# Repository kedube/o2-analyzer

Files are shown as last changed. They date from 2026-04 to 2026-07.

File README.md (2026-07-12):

# O2 Analyzer Firmware

PlatformIO firmware for an Arduino-based nitrox / oxygen analyzer with a 128x64 SSD1306 OLED, ADS1115 ADC, buzzer feedback, EEPROM-backed calibration, and a single-button UI. The code is originally based on [Eunjae Im's OLED nitrox analyzer project](http://ejlabs.net/arduino-oled-nitrox-analyzer). 

This firmware accompanies the Divetech nitrox analyzer enclosure designed by Tony Land and is intended to build cleanly in Visual Studio Code with current PlatformIO and Adafruit libraries.

## Images

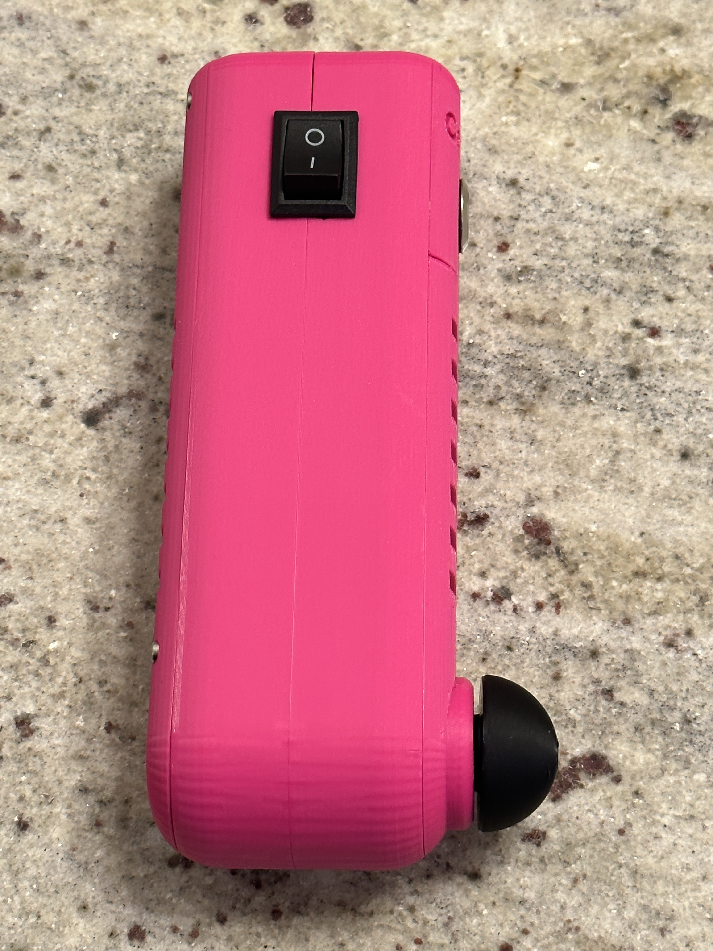
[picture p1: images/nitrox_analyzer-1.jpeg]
O2 analyzer front view


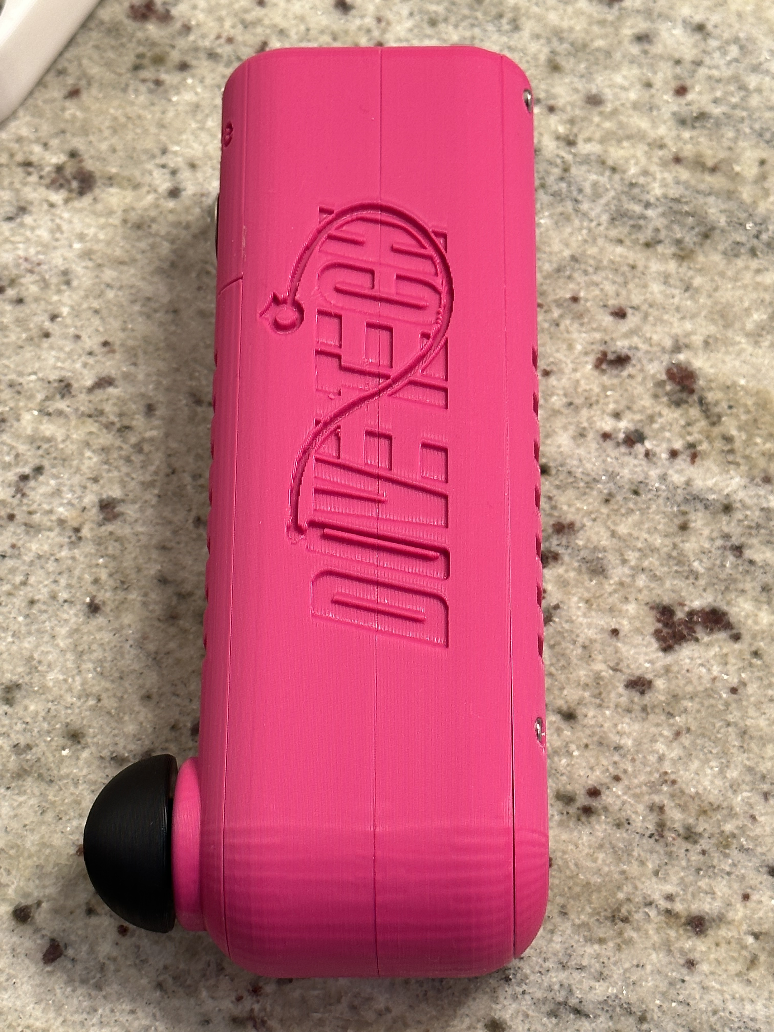
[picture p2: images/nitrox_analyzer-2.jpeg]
O2 analyzer display close-up


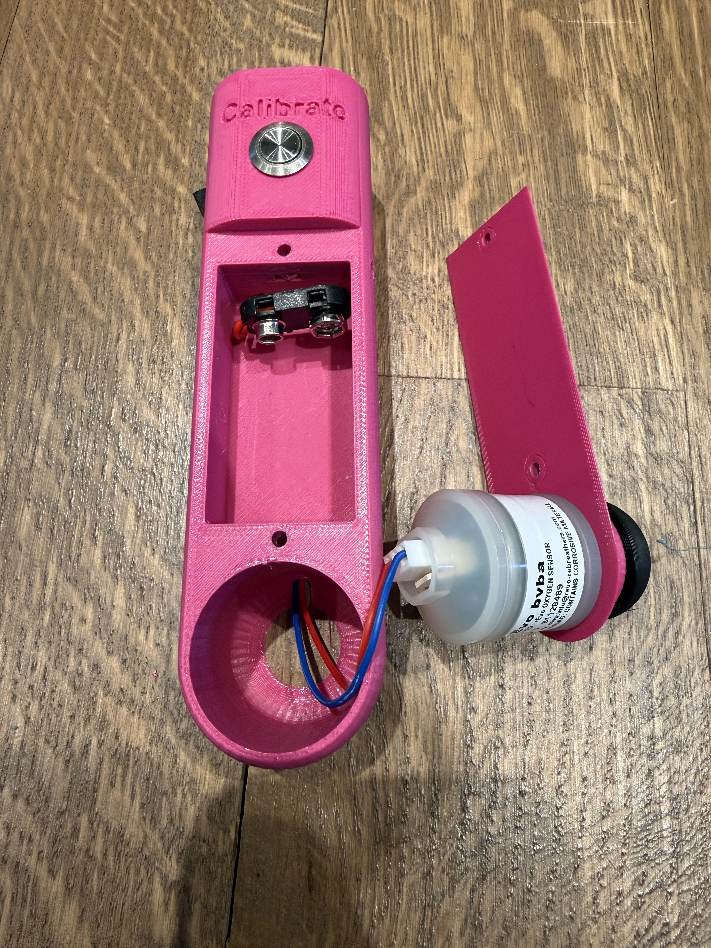
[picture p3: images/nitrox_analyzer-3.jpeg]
O2 analyzer internal wiring


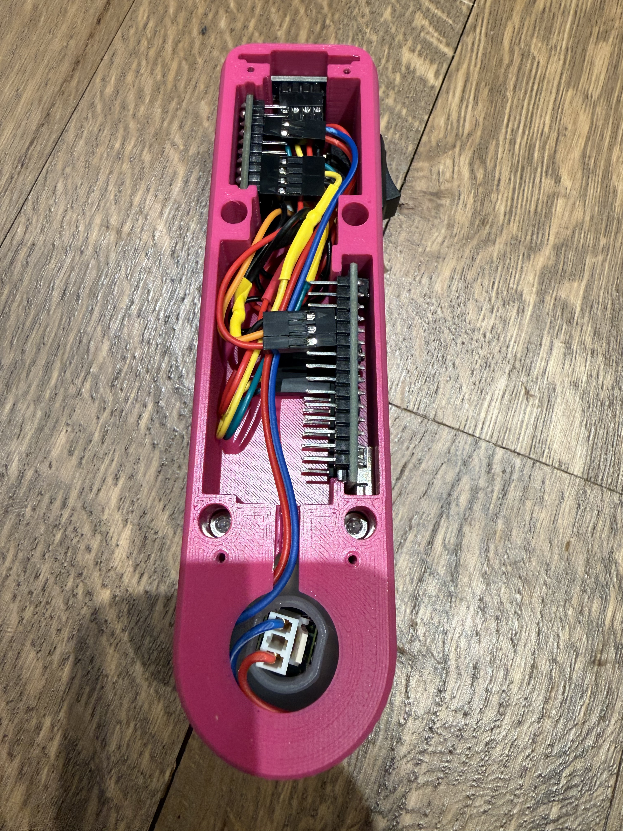
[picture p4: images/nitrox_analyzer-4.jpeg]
O2 analyzer alternate assembly view


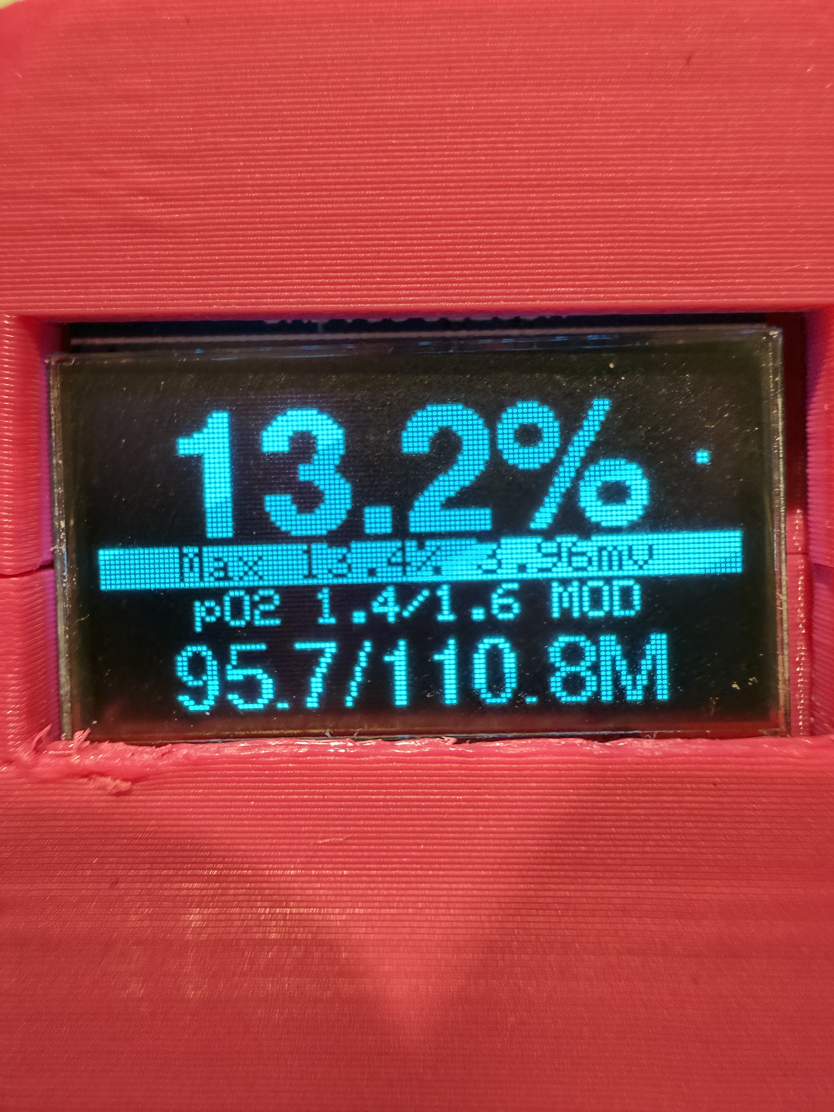
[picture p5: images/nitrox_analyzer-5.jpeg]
O2 analyzer alternate assembly view


## OLED Screenshots

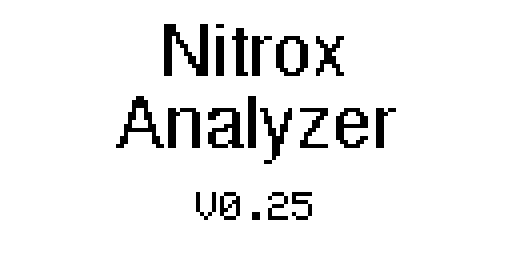
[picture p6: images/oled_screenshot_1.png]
OLED screenshot 1
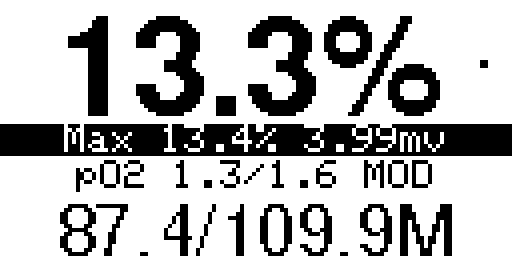
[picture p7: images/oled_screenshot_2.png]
OLED screenshot 2
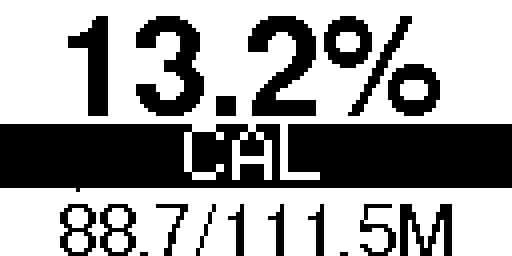
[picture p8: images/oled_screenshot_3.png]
OLED screenshot 3
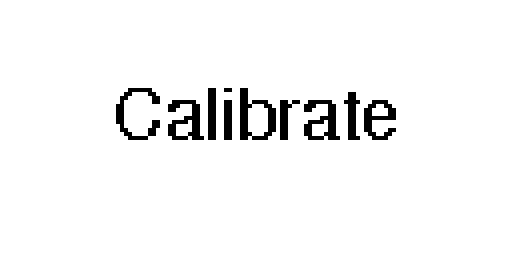
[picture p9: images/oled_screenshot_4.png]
OLED screenshot 4
|  |  |  |  |
| --- | --- | --- | --- |
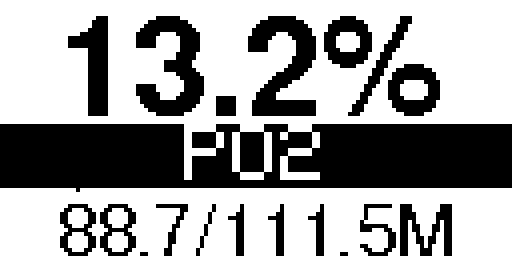
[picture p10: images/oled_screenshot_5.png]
OLED screenshot 5
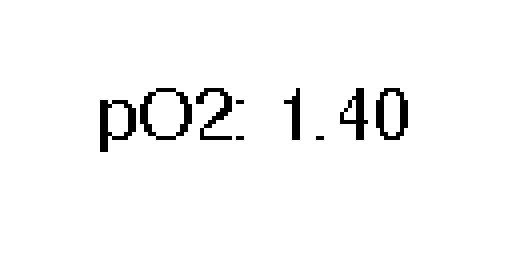
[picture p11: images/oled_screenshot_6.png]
OLED screenshot 6
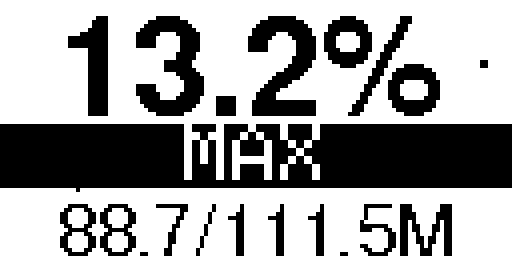
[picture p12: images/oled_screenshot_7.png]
OLED screenshot 7
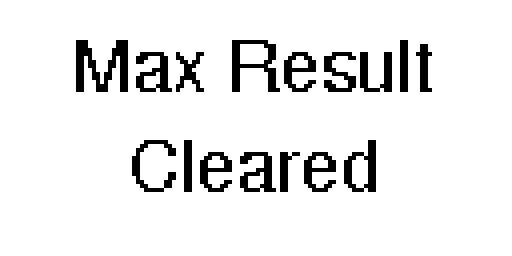
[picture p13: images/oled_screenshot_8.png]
OLED screenshot 8
|  |  |  |  |

The current project target is an Arduino Nano ATmega328P with the new bootloader configuration.

## Features

- Reads the oxygen sensor through an ADS1115 differential input
- Smooths sensor readings with a lightweight local moving average
- Displays live O2 percentage, max reading, sensor millivolts, and MOD values
- Stores calibration data and user settings (buzzer, pO2 selection, MOD units) in EEPROM so they survive power cycles
- Uses a single button hold-menu for lock, calibration, pO2 selection, buzzer toggle, MOD unit toggle, and max-clear actions
- Uses centered OLED layouts and subsetted Adafruit GFX fonts to preserve the condensed UI while reducing flash usage
- Skips redundant OLED redraws to reduce display flicker and unnecessary work
- Powers itself down after 5 minutes of inactivity, with a 10-second cancellable on-screen warning; a button press wakes it straight back to the live reading

## Hardware

- Arduino Nano ATmega328P (new bootloader)
- SSD1306 OLED display, 128x64, I2C, address `0x3C`
- ADS1115 ADC
- Oxygen sensor wired to ADS1115 differential input `A0/A1`
- Push button on digital pin `2`
- Buzzer on digital pin `3`

## Wiring Diagram

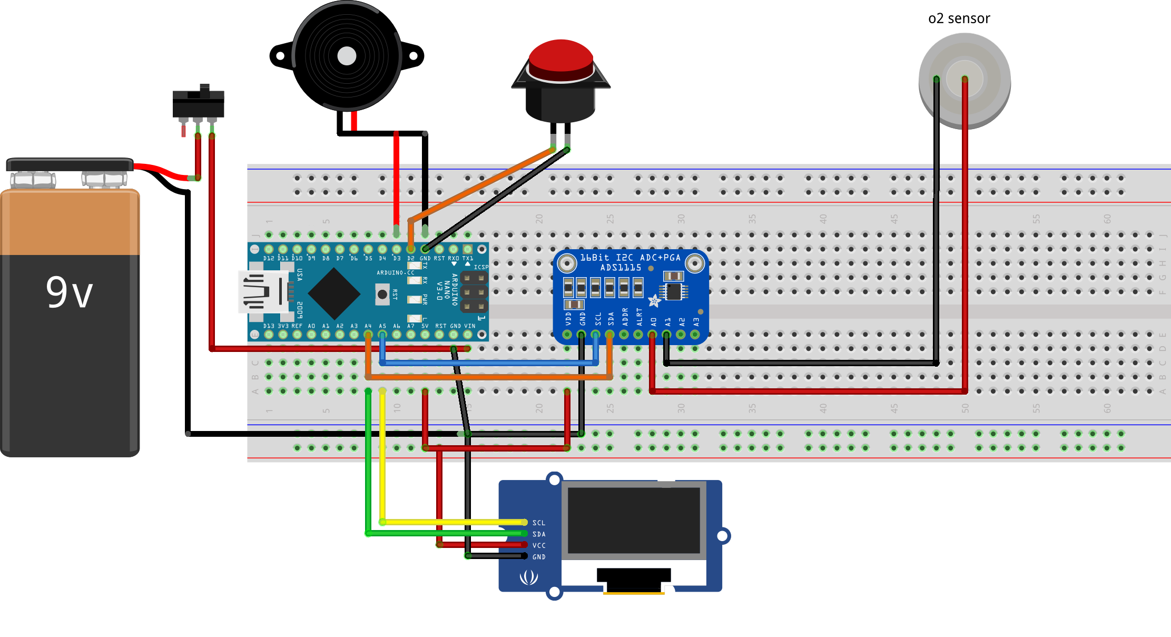
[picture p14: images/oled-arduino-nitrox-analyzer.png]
OLED Arduino nitrox analyzer wiring diagram


Connection details, based on the original wiring notes:

- ADS1115: `VDD` to `5V`, `GND` to `GND`, `SCL` to `A5`, `SDA` to `A4`
- OLED display: `VCC` to `5V`, `GND` to `GND`, `SCL` to `A5`, `SDA` to `A4`
- Push button: one side to `GND`, the other to `D2`
- Buzzer: positive to `D3`, negative to `GND`
- Oxygen sensor: positive to ADS1115 `A0`, negative to ADS1115 `A1`
- Battery: positive to `VIN` through the rocker switch, negative to `GND`

The OLED and ADS1115 share the same I2C bus, so both modules connect to the Nano's `A4`/`SDA` and `A5`/`SCL` pins.

The original ejlabs notes also caution that a `9V` battery is a poor long-term power choice for Arduino projects and that reverse polarity on `VIN` can damage the onboard regulator.

## Enclosure And 3D Files

The printable enclosure is based on [Tony Land's Divetech nitrox analyzer housing](https://web.archive.org/web/20240414033725/https://www.divetech.com/post/the-20-nitrox-analyzer) and was remixed to fit commonly available `0.96"` `128x64` OLED modules whose display glass is larger than the original front-panel cutout.

The STL files are available from:

- GitHub: [hardware/3d-models](hardware/3d-models)
- Printables: [Divetech nitrox analyzer enclosure](https://www.printables.com/model/554448-oled-modification-for-divetech-nitrox-analyzer)

Assembly Photos:

- [hardware/assembly/README.md](hardware/assembly/README.md)

## Bill Of Materials

The Printables model lists these materials for the physical build, with example source links for several parts:

- [Arduino Nano](https://a.co/d/hmOA4fG)
- [`.96 inch` `128x64` OLED screen](https://a.co/d/fV3mk5q)
- [ADS1115 analog-to-digital converter](https://a.co/d/guoRf2Z)
- [Rocker switch](https://a.co/d/8EYTpxj), `13 x 19 mm` panel mount
- [Push button](https://a.co/d/2yPEBGB), `12 mm` diameter
- [`9 mm` electronic buzzer](https://a.co/d/0gzqU7lq)
- `6` M3x10 mm hex-head screws
- `4` M2x10 mm hex-head screws
- Molex terminals
- [`9V` battery clip connector](https://a.co/d/7T9FWCe)
- `9V` battery
- O2 sensor (with Molex 3-Pin Connector)
- Wire and solder

## Button Actions

- Tap: lock screen
- Hold for the menu-entry delay: enter the hold menu at `CAL`
- Keep holding: cycle through `CAL` -> `PO2` -> `BUZ` -> `MOD` -> `MAX` -> normal screen, then repeat
- Release while a menu label is shown: run that action
- Release while the normal screen is shown during the cycle: exit without changing anything
- Hold for `1` second while powering on: reset the saved settings (buzzer, pO2, MOD units) to defaults; calibration is kept. Waking from auto power-off never triggers this reset.
- Press during the auto power-off countdown: cancel the shutdown and stay on
- Press after auto power-off: wake the analyzer; it skips the splash screen and returns straight to the live reading

## Project Layout

```text
o2-analyzer/
├── .gitignore
├── hardware/
│   ├── 3d-models/
│   │   ├── back_cap.stl
│   │   ├── back_half.stl
│   │   ├── battery-sensor_cover.stl
│   │   ├── flow_restrictor.stl
│   │   ├── flow_restrictor_10mm.stl
│   │   ├── flow_restrictor_115mm.stl
│   │   ├── flow_restrictor_12mm.stl
│   │   ├── flow_restrictor_95mm.stl
│   │   ├── flow_restrictor_9mm.stl
│   │   ├── front_half_v2.stl
│   │   └── front_upper_cover.stl
│   └── assembly/
│       ├── assembly-[1-7].jpg
│       ├── assembly-8.png
│       └── README.md
├── images/
│   ├── nitrox_analyzer-[1-5].jpeg
│   ├── oled-arduino-nitrox-analyzer.png
│   └── oled_screenshot_[1-8].png
├── include/
│   ├── display_ui.h
│   ├── FreeSans9pt7bSubset.h
│   ├── FreeSansBold18pt7bSubset.h
│   └── settings.h
├── LICENSE
├── platformio.ini
├── README.md
├── src/
│   ├── display_ui.cpp
│   └── main.cpp
└── tools/
    └── oled_capture.py
```

- [src/display_ui.cpp](src/display_ui.cpp): OLED rendering and text/layout helpers
- [include/display_ui.h](include/display_ui.h): display snapshot model and rendering function declarations
- [src/main.cpp](src/main.cpp): firmware logic, UI rendering, button handling, calibration, and sensor processing
- [include/FreeSans9pt7bSubset.h](include/FreeSans9pt7bSubset.h): subset small UI font
- [include/FreeSansBold18pt7bSubset.h](include/FreeSansBold18pt7bSubset.h): subset large percentage font
- [include/settings.h](include/settings.h): firmware configuration constants for pins, timings, display settings, and calibration defaults
- [.gitignore](.gitignore): ignores PlatformIO build outputs, editor settings, and macOS metadata
- [hardware/assembly/README.md](hardware/assembly/README.md): assembly image gallery
- [hardware/3d-models](hardware/3d-models): printable enclosure and accessory STL files
- [platformio.ini](platformio.ini): PlatformIO target, libraries, and build flags
- [tools/oled_capture.py](tools/oled_capture.py): converts a captured SSD1306 framebuffer dump into a PNG image

## Build Configuration

Current PlatformIO configuration:

```ini
[platformio]
default_envs = nano

[env]
framework = arduino
monitor_speed = 57600
upload_speed = 115200
build_flags =
  -D SSD1306_NO_SPLASH
  -D SERIAL_RX_BUFFER_SIZE=16
  -D SERIAL_TX_BUFFER_SIZE=16
lib_deps =
  adafruit/Adafruit GFX Library @ ^1.12.6
  adafruit/Adafruit SSD1306 @ ^2.5.16
  adafruit/Adafruit ADS1X15 @ ^2.6.2

[env:nano]
platform = atmelavr
board = nanoatmega328new
```

Install PlatformIO with either the VS Code PlatformIO extension or the CLI:

```sh
python3 -m pip install --user platformio
```

## Visual Studio Code Setup

To clone and build this firmware from Visual Studio Code:

1. Install [Visual Studio Code](https://code.visualstudio.com/).
2. Install the following extensions from the VS Code marketplace:
  - [PlatformIO IDE](https://marketplace.visualstudio.com/items?itemName=platformio.platformio-ide) for dependency management, building, uploading, and serial monitoring.
  - [C/C++](https://marketplace.visualstudio.com/items?itemName=ms-vscode.cpptools) for code navigation and IntelliSense.
3. Ensure `git` is installed on your machine.
4. Open the VS Code Command Palette and run `Git: Clone`.
5. Paste the repository URL and choose a local folder.
6. Open the cloned `o2-analyzer` folder in VS Code.
7. Wait for PlatformIO to finish initializing the project and installing toolchains and libraries.

You can also clone from a terminal:

```sh
git clone https://github.com/kedube/o2-analyzer.git
cd o2-analyzer
code .
```

### Build In VS Code

After the folder is open in VS Code:

1. Click the PlatformIO alien-head icon in the Activity Bar.
2. Under `PROJECT TASKS` > `nano`, run `Build`.
3. Connect the Arduino Nano over USB.
4. Run `Upload` to flash the firmware.
5. Run `Monitor` to open the serial console at `57600` baud.

PlatformIO uses the default `nano` environment defined in [platformio.ini](platformio.ini).

## Configuration Options

This project has two main configuration layers: PlatformIO project settings in [platformio.ini](platformio.ini) and firmware settings in [include/settings.h](include/settings.h).

### PlatformIO Options

Common options you may want to change in [platformio.ini](platformio.ini):

- `default_envs`: selects the default build target. The current default is `nano`.
- `board`: selects the Arduino board definition. The current board is `nanoatmega328new`.
- `monitor_speed`: sets the serial monitor baud rate. The firmware uses `57600`.
- `upload_speed`: sets the upload baud rate. The current value is `115200`.
- `upload_port`: optional manual serial port override if auto-detection fails.
- `build_flags`: compile-time defines passed to the build. `SSD1306_NO_SPLASH` is enabled to save flash.
- `SERIAL_RX_BUFFER_SIZE` and `SERIAL_TX_BUFFER_SIZE`: reduced to `16` bytes to preserve SRAM for the SSD1306 framebuffer on the ATmega328P.
- `lib_deps`: PlatformIO-managed library dependencies.

Example manual serial port configuration:

```ini
[env:nano]
platform = atmelavr
board = nanoatmega328new
upload_port = /dev/tty.usbserial-0001
```

### Firmware Options

Hardware and behavior settings are defined in [include/settings.h](include/settings.h). After changing these values, rebuild and upload the firmware.

- `kScreenAddress`: I2C address for the SSD1306 display. Default: `0x3C`.
- `kButtonPin`: button input pin. Default: `2`.
- `kBuzzerPin`: buzzer output pin. Default: `3`.
- `kBuzzerEnabledByDefault`: sets whether the buzzer starts enabled on first boot, before a saved setting exists. Default: `true`.
- `kBootDebugLogging`: enables verbose startup logging over serial for boot diagnostics. Default: `false`.
- `kModInFeetByDefault`: sets whether MOD values default to feet instead of meters on first boot, before a saved setting exists. Default: `true`.
- `kSerialBaudRate`: serial monitor and screenshot capture baud rate. Default: `57600`.
- `kScreenshotCommand`: serial command character used to request a display dump. Default: `s`.
- `kOledReset`: OLED reset pin passed to the display driver. Default: `4`.
- `kRaSize`: moving-average sample window for sensor smoothing. Default: `20`.
- `kSensorSampleIntervalMs`: how often a new sensor sample is added to the moving average. Default: `50` ms.
- `kMenuEntryHoldSeconds`: button hold time before the menu appears. Default: `2` seconds.
- `kMenuStepIntervalMs`: time each menu slot stays active before advancing to the next label or back to the normal screen. Default: `1100` ms.
- `kStatusScreenMs`: how long temporary status screens remain visible. Default: `1200` ms.
- `kLockScreenMs`: lock-screen display duration. Default: `5000` ms.
- `kSplashScreenMs`: startup splash screen duration. Default: `1200` ms.
- `kAutoPowerOffMs`: inactivity time before the analyzer powers itself down. Default: `5` minutes.
- `kPowerOffWarningSeconds`: countdown length of the cancellable auto power-off warning screen. Default: `10` seconds.
- `kActivityDeltaTenths`: O2 change (in tenths of a percent) that counts as activity and defers auto power-off. Default: `3` (0.3%).
- `kAirCalibrationPercent`: oxygen percentage used for air calibration. Default: `20.9`.
- `kDefaultMinPo2`: selected working pO2 on first boot, before a saved setting exists. Default: `1.40`.
- `kDefaultMaxPo2`: default maximum pO2 used in MOD calculations. Default: `1.60`.
- `kMinValidCalibration` and `kMaxValidCalibration`: accepted calibration range guardrails.
- `kCalibrationAddress` and `kSettingsAddress`: EEPROM byte offsets of the calibration record and the persisted user-settings record (buzzer, pO2, MOD units). Each record is validated with its own magic byte (`kCalibrationMagic`, `kSettingsMagic`).
- `kWakeMarkerAddress`: EEPROM byte flagging the next reboot as an auto power-off wake, so the held wake press is not mistaken for a settings reset.
- `kSettingsResetHoldMs`: how long the button must be held during power-on to reset the saved settings. Default: `1000` ms.

Change these only if your hardware wiring, display address, or operating assumptions differ from the current build.

## Build

From the repository root:

```sh
platformio run
```

## Upload

```sh
platformio run --target upload
```

If PlatformIO does not auto-detect the serial port on your machine, add `upload_port` to [platformio.ini](platformio.ini).

## Serial Monitor

```sh
platformio device monitor --baud 57600
```

## Display Screenshot Utility

The repository includes [tools/oled_capture.py](tools/oled_capture.py), a small host-side utility that converts a `128x64` Adafruit SSD1306 framebuffer dump into a PNG.

It accepts any of these inputs:

- A raw `1024`-byte framebuffer file in Adafruit SSD1306 page order.
- An ASCII hex dump containing the same `1024` bytes.
- A serial frame with the header `OLED_FRAME 128 64` followed by `1024` raw bytes.

The firmware supports live screenshot capture over USB serial. It listens at `57600` baud and sends the current OLED framebuffer when it receives the `s` command.

Convert a saved raw framebuffer dump into a PNG:

```sh
python3 tools/oled_capture.py oled-frame.bin --output oled-screenshot.png
```

Convert a hex dump into a larger image:

```sh
python3 tools/oled_capture.py oled-frame.txt --format hex --scale 6 --output oled-screenshot.png
```

Capture a live screenshot directly from the analyzer:

```sh
python3 -m pip install pyserial
python3 tools/oled_capture.py --serial /dev/tty.usbserial-0001 --output oled-screenshot.png
```

The script sends `s` automatically before waiting for the frame. If you change the firmware command character, pass the new value with `--command`.

## Dependencies

PlatformIO installs these libraries automatically:

- Adafruit GFX Library
- Adafruit SSD1306
- Adafruit ADS1X15

Core Arduino libraries used directly by the firmware:

- Wire
- EEPROM

## Calibration Notes

- Calibration is based on ambient air and uses `20.9%` oxygen as the reference point.
- Calibration is stored in EEPROM with a validation marker.
- If saved calibration data is missing or invalid, the firmware forces a new calibration during startup.
- The firmware constrains calibration input to a sane range before saving it.

## Erasing The EEPROM

The firmware only uses two small EEPROM records plus a wake-marker byte (calibration at bytes `0-2`, user settings at bytes `8-10`, wake marker at byte `12`), and the records can be refreshed without an erase: hold the button for `1` second during power-on to reset settings, and run `CAL` from the hold menu to overwrite calibration. For a full wipe, upload a temporary sketch that writes `0xFF` to all `1024` bytes, then re-upload the analyzer firmware. Note that `avrdude` cannot touch EEPROM over plain USB serial because the optiboot bootloader does not support it; direct EEPROM access requires an ISP programmer.

## Firmware Notes

- The splash bitmap in Adafruit SSD1306 is disabled at build time to save flash.
- The small and large UI fonts are subsetted to only the glyphs used by the analyzer screens.
- Display updates are cached so unchanged frames are not redrawn.
- Buzzer, pO2 selection, and MOD unit preferences are written to EEPROM when changed from the hold menu and restored at boot. Holding the button for `1` second during power-on resets them to defaults without touching calibration.
- Sensor samples are collected every `50` ms independently of the `200` ms display refresh, so the moving average settles in about one second.
- The ADS1115 runs in continuous conversion mode, so sensor reads return the latest completed conversion instead of blocking while a new one runs.
- The main loop puts the CPU into idle sleep between timer ticks to reduce battery drain.
- After `5` minutes without a button press or a meaningful O2 change, the firmware first shows a beeping `AUTO OFF` countdown for `10` seconds; pressing the button during the countdown cancels the shutdown. If it runs out, the firmware shows `AUTO OFF`, blanks the display, drops the ADS1115 back to its powered-down single-shot mode, and puts the MCU into power-down sleep. Pressing the button wakes it through a watchdog reset; a wake marker in EEPROM makes the wake boot skip the splash screen and return straight to the live reading, and ensures the held wake press is never mistaken for the hold-to-reset-settings gesture. Note the Nano's onboard regulator and power LED still draw a few milliamps, so the rocker switch remains the true off switch; auto power-off is a failsafe for a forgotten unit.
- Current builds are comfortably within ATmega328P limits.

## Origin

This project sits on top of earlier mechanical and firmware work:

- The enclosure remix is based on Tony Land's Divetech nitrox analyzer housing.
- The firmware originates from Eunjae Im's OLED nitrox analyzer project and has been updated here for current OLED hardware, newer Adafruit libraries, and a smoother VS Code and PlatformIO workflow.
- The Printables project page for this build is [OLED modification for Divetech nitrox analyzer](https://www.printables.com/model/554448-oled-modification-for-divetech-nitrox-analyzer).

Background references:

- http://ejlabs.net/arduino-oled-nitrox-analyzer
- https://web.archive.org/web/20240414033725/https://www.divetech.com/post/the-20-nitrox-analyzer

## License

Licensed under GNU GPL v3. See [LICENSE](LICENSE).

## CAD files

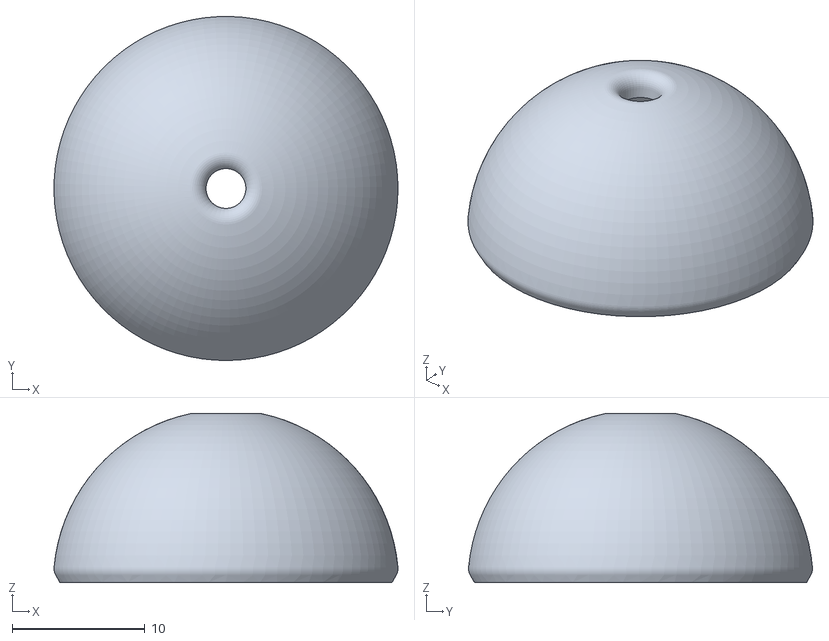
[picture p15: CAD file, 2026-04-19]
hardware/3d-models/flow_restrictor.stl
25.9 x 25.9 x 12.7

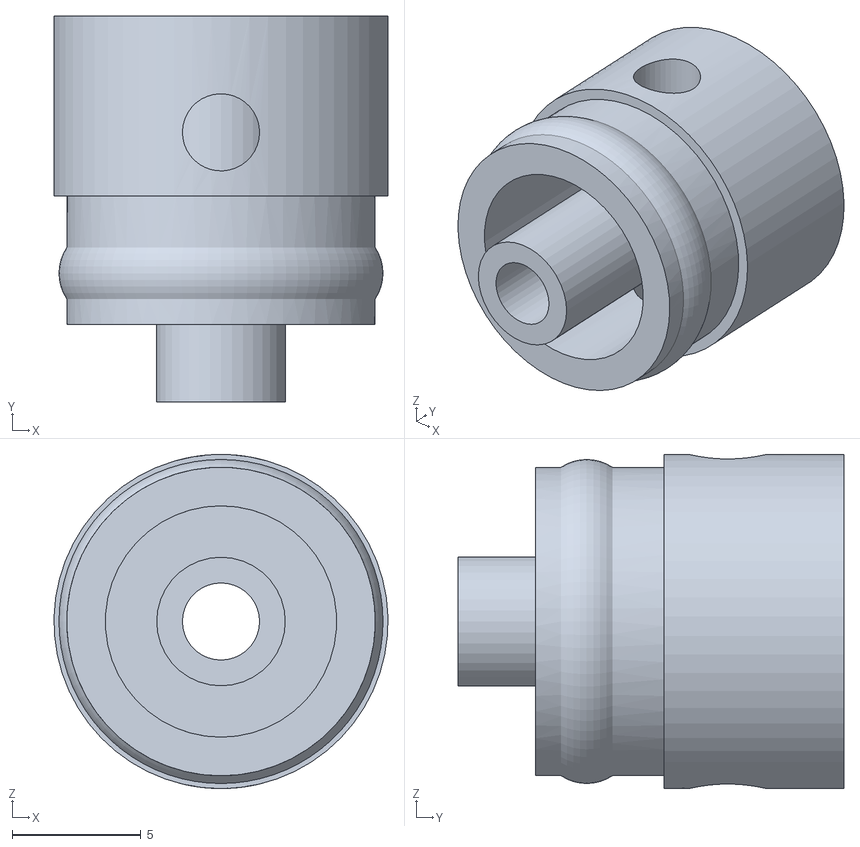
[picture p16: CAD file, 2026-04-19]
hardware/3d-models/flow_restrictor_12mm.stl
13.0 x 15.0 x 13.0

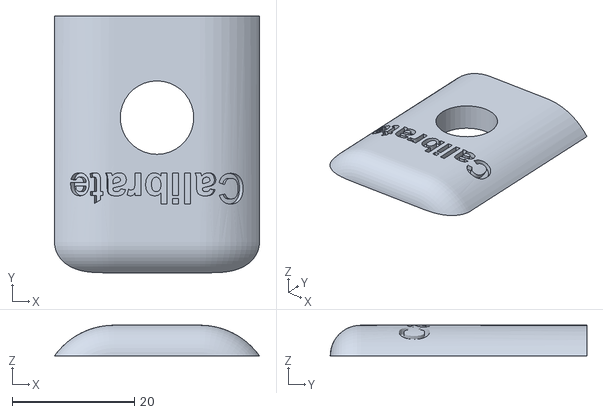
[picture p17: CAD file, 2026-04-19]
hardware/3d-models/front_upper_cover.stl
33.5 x 41.9 x 5.00

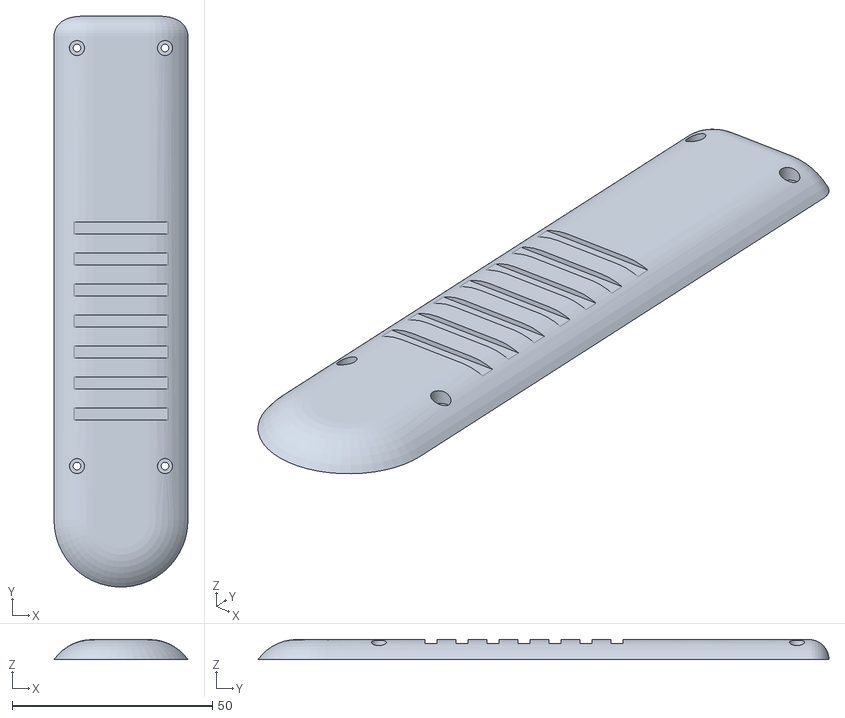
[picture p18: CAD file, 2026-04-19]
hardware/3d-models/back_cap.stl
33.5 x 142.7 x 5.00

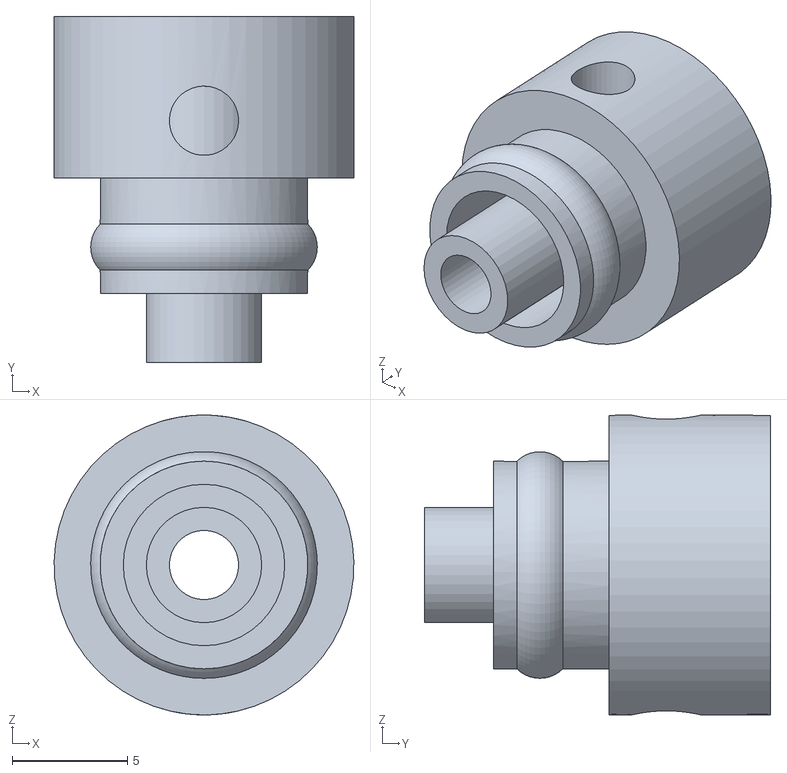
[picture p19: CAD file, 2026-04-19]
hardware/3d-models/flow_restrictor_9mm.stl
13.0 x 15.0 x 13.0

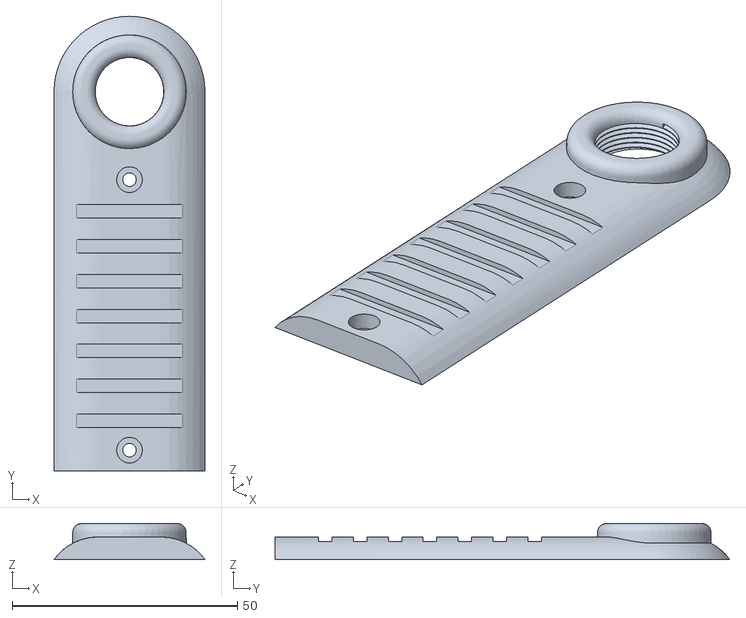
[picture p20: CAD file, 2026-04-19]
hardware/3d-models/battery-sensor_cover.stl
33.5 x 100.8 x 8.00

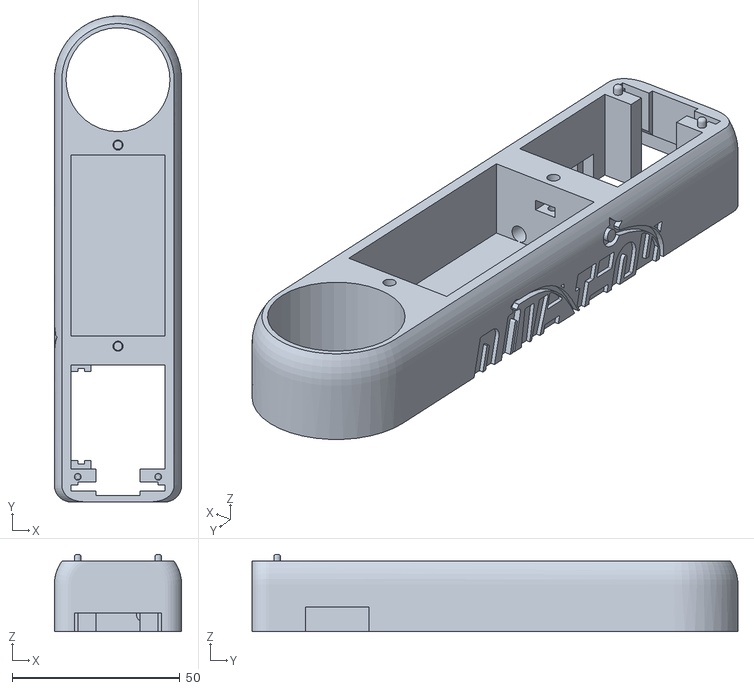
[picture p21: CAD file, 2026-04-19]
hardware/3d-models/front_half_v2.stl
38.0 x 145.0 x 23.0

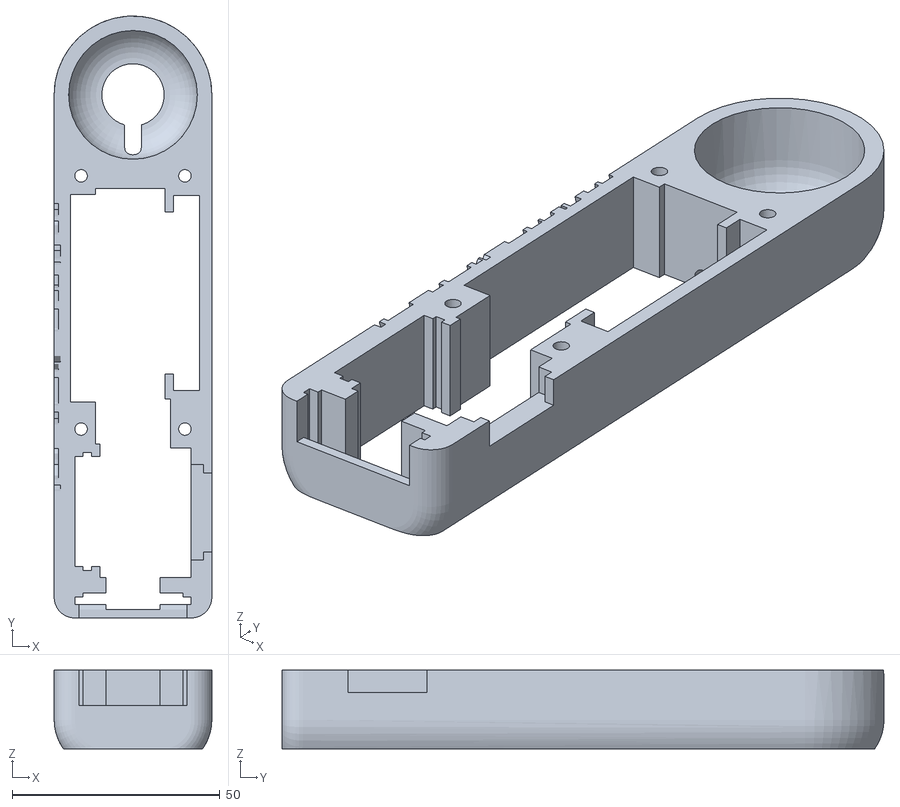
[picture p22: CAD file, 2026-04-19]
hardware/3d-models/back_half.stl
38.0 x 145.0 x 19.0

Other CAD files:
hardware/3d-models/flow_restrictor_115mm.stl
hardware/3d-models/flow_restrictor_10mm.stl
hardware/3d-models/flow_restrictor_95mm.stl

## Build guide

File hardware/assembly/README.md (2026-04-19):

# Assembly Photos

This folder contains step-by-step assembly reference images.

## Gallery

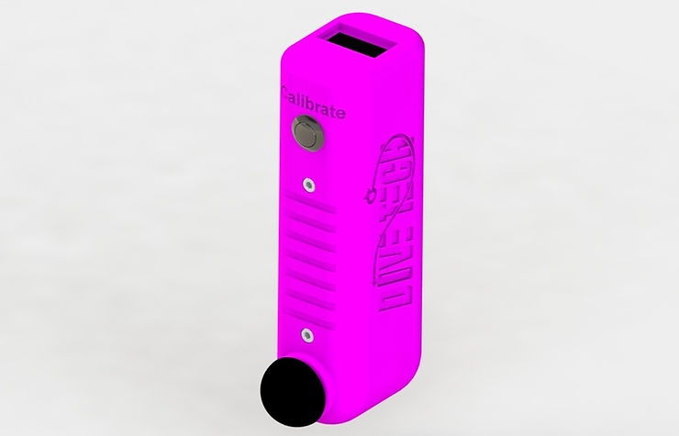
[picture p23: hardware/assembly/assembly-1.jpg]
Assembly step 1


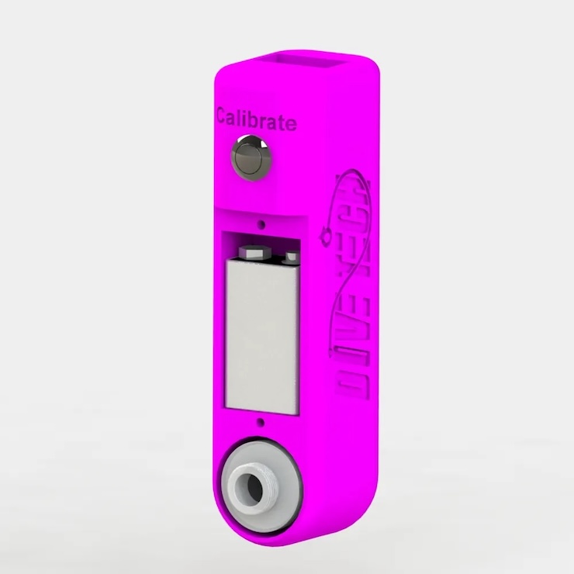
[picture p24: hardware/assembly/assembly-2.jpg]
Assembly step 2


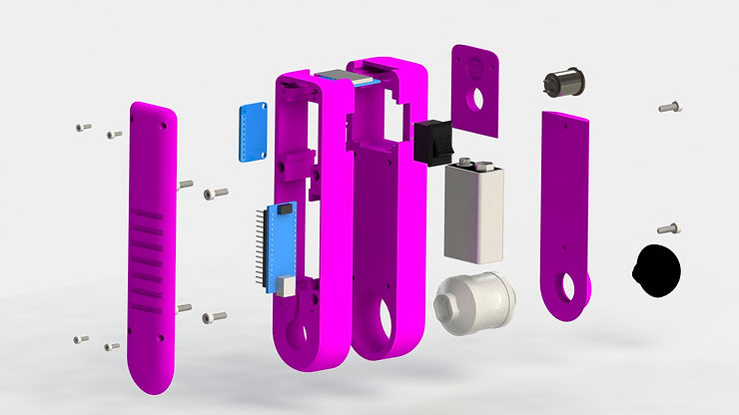
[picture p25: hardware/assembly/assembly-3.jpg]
Assembly step 3


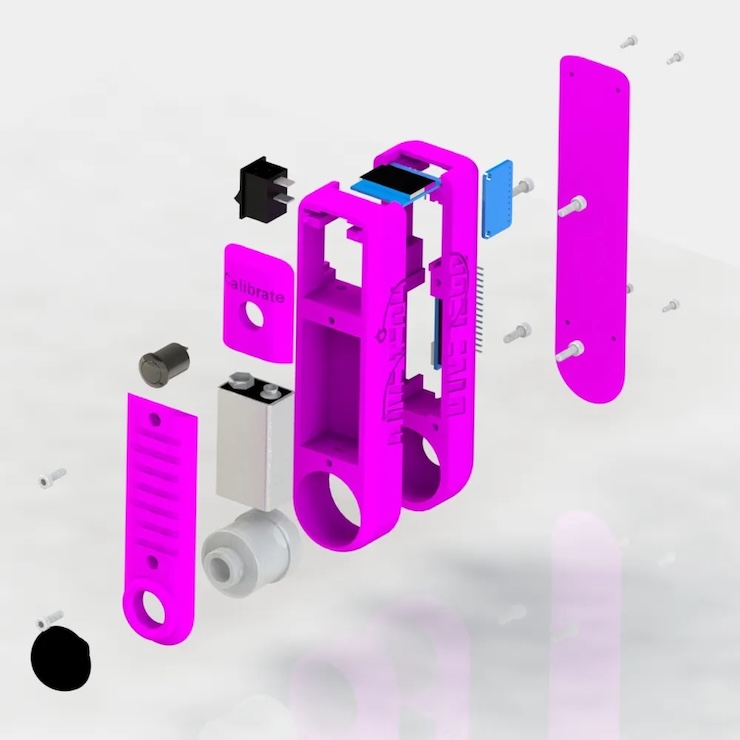
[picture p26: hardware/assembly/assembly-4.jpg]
Assembly step 4


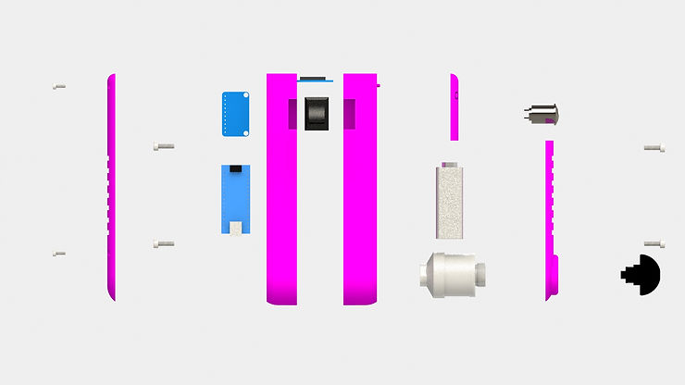
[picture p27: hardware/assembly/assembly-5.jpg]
Assembly step 5


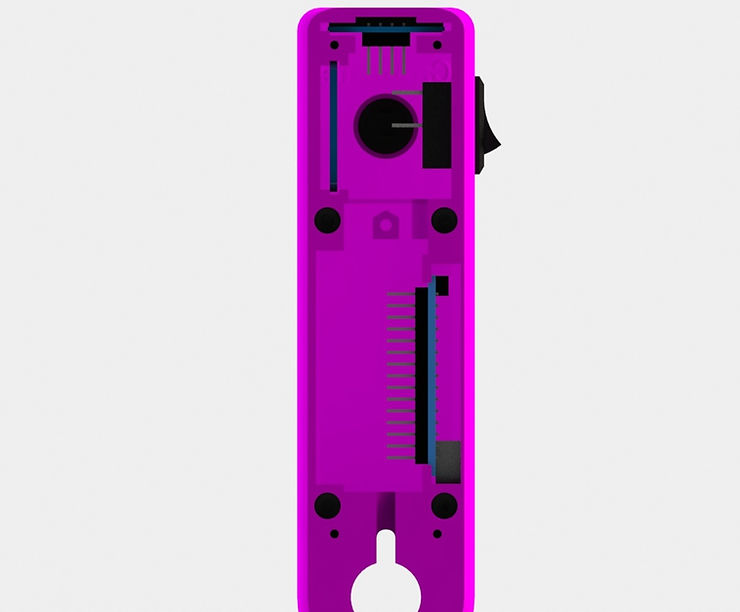
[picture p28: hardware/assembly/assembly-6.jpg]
Assembly step 6


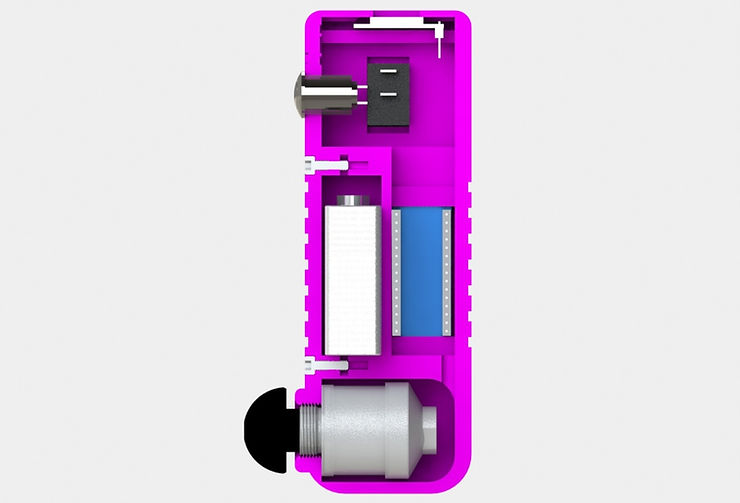
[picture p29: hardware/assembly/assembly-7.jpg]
Assembly step 7


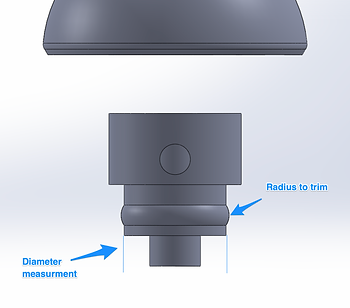
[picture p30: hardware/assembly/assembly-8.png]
Assembly step 8


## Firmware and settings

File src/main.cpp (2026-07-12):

/*****************************************************************************
* 
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
*****************************************************************************/

#include <Arduino.h>
#include <Wire.h>
#include <avr/sleep.h>
#include <avr/wdt.h>
#include <Adafruit_GFX.h>
#include <Adafruit_SSD1306.h>
#include <Adafruit_ADS1X15.h>
#include <EEPROM.h>
#include "FreeSansBold18pt7bSubset.h"
#include "FreeSans9pt7bSubset.h"
#include "display_ui.h"
#include "settings.h"

struct CalibrationData {
  uint8_t magic;
  uint16_t value;
};

struct SettingsData {
  uint8_t magic;
  uint8_t maxPo1Tenths;
  uint8_t flags;
};

constexpr uint8_t kSettingsBuzzerFlag = 0x01;
constexpr uint8_t kSettingsModInFeetFlag = 0x02;
constexpr uint8_t kMinPo2Tenths = 13;
constexpr uint8_t kMaxPo2Tenths = 15;

struct AnalyzerState {
  float calibrationValue = 0.0F;
  float calibrationScale = 0.0F;
  float resultMax = 0.0F;
  float maxPo1 = kDefaultMinPo2;
  bool buzzerEnabled = kBuzzerEnabledByDefault;
  bool modInFeet = kModInFeetByDefault;
  unsigned long millisHeld = 0;
  byte previousButtonState = HIGH;
  unsigned long firstPressTime = 0;
  int activeFrames = 0;
  unsigned long lastUiRefreshMs = 0;
  unsigned long lastSensorSampleMs = 0;
  unsigned long lastActivityMs = 0;
  int16_t activityResultTenths = 0;
  bool ignoreHeldButton = false;
};

struct SensorAverage {
  int16_t samples[kRaSize] = {};
  int32_t sum = 0;
  uint8_t count = 0;
  uint8_t nextIndex = 0;

  void clear() {
    sum = 0;
    count = 0;
    nextIndex = 0;
    for (uint8_t i = 0; i < kRaSize; ++i) {
      samples[i] = 0;
    }
  }

  void addValue(int16_t value) {
    if (count < kRaSize) {
      samples[nextIndex] = value;
      sum += value;
      ++count;
    } else {
      sum -= samples[nextIndex];
      samples[nextIndex] = value;
      sum += value;
    }

    ++nextIndex;
    if (nextIndex >= kRaSize) {
      nextIndex = 0;
    }
  }

  float average() const {
    if (count == 0) {
      return 0.0F;
    }
    return static_cast<float>(sum) / static_cast<float>(count);
  }
};

int calibrate();
bool readCalibration(float &value);
void writeCalibration(uint16_t value);
void readSettings();
void writeSettings();
void clearSettings();
bool consumeWakeMarker();
bool settingsResetRequested();
bool isCalibrationValid(float value);
void pauseWithPolling(unsigned long durationMs);
void readSensor();
void sampleSensorIfDue();
void powerDown();
bool powerOffWarningCancelled();
void analyze();
void invalidateDisplaySnapshot();
void handleSerialCommands();
void dumpDisplayBuffer();
void logBootMessage(const __FlashStringHelper *message);
void updateCalibrationScale(float calibrationValue);
int16_t roundToTenths(float value);
int16_t roundToHundredths(float value);
uint8_t menuIndexForHoldDuration(unsigned long heldDurationMs);
uint8_t currentHoldMenu();
void runHoldMenuAction(uint8_t menuIndex);
void po2_change();
void buzzer_toggle();
void mod_unit_toggle();
void max_clear();

SensorAverage sensorAverage;
AnalyzerState state;
DisplaySnapshot lastDisplaySnapshot;

Adafruit_ADS1115 ads;
Adafruit_SSD1306 display(kScreenWidth, kScreenHeight, &Wire, kOledReset);

constexpr unsigned long kMsPerSecond = 1000;
constexpr unsigned long kMenuEntryHoldMs = kMenuEntryHoldSeconds * kMsPerSecond;
constexpr unsigned long kButtonDebounceMs = 200;
constexpr unsigned long kUiRefreshIntervalMs = 200;
constexpr unsigned long kPausePollMs = 10;
// One ADS1115 conversion takes 4ms at 250SPS; spacing warmup reads by a bit
// more guarantees each read sees a fresh conversion in continuous mode.
constexpr unsigned long kAdsConversionSpacingMs = 5;
constexpr uint8_t kHoldMenuItemCount = 5;
static_assert(kMenuStepIntervalMs > 0, "kMenuStepIntervalMs must be greater than 0");

/*
 Calculate MOD (Maximum Operating Depth)
*/
float calculateModDepth(float percentage, float ppo2 = 1.4F) {
  if (percentage <= 0.0F) {
    return 0.0F;
  }

  const float depthMeters = 10.0F * ((ppo2 / (percentage / 100.0F)) - 1.0F);
  if (!state.modInFeet) {
    return depthMeters;
  }

  return depthMeters * kFeetPerMeter;
}

void beep(int x = 1) {  // make beep for x time
  if (!state.buzzerEnabled) {
    return;
  }

  for (int i = 0; i < x; i++) {
    tone(kBuzzerPin, 2800, 100);
    pauseWithPolling(200);
  }
  noTone(kBuzzerPin);
}

void pauseWithPolling(unsigned long durationMs) {
  const unsigned long startMs = millis();
  while ((millis() - startMs) < durationMs) {
    handleSerialCommands();
    sampleSensorIfDue();
    delay(kPausePollMs);
  }
}

void logBootMessage(const __FlashStringHelper *message) {
  if (!kBootDebugLogging) {
    return;
  }

  Serial.println(message);
}

void dumpDisplayBuffer() {
  const uint8_t *buffer = display.getBuffer();
  const size_t bufferSize =
      static_cast<size_t>(kScreenWidth) * static_cast<size_t>(kScreenHeight) / 8U;

  Serial.print(F("OLED_FRAME "));
  Serial.print(kScreenWidth);
  Serial.print(' ');
  Serial.println(kScreenHeight);
  Serial.write(buffer, bufferSize);
  Serial.flush();
}

void handleSerialCommands() {
  while (Serial.available() > 0) {
    const int input = Serial.read();
    if (input == kScreenshotCommand || input == 'S') {
      dumpDisplayBuffer();
    }
  }
}

void readSensor() {
  // The ADS1115 free-runs in continuous mode; this just fetches the latest
  // completed conversion instead of blocking on a new one.
  sensorAverage.addValue(ads.getLastConversionResults());
}

void sampleSensorIfDue() {
  const unsigned long now = millis();
  if ((now - state.lastSensorSampleMs) >= kSensorSampleIntervalMs) {
    state.lastSensorSampleMs = now;
    readSensor();
  }
}

void invalidateDisplaySnapshot() {
  lastDisplaySnapshot.initialized = false;
}

int16_t roundToTenths(float value) {
  const float scaled = value * 10.0F;
  return static_cast<int16_t>(scaled >= 0.0F ? scaled + 0.5F : scaled - 0.5F);
}

int16_t roundToHundredths(float value) {
  const float scaled = value * 100.0F;
  return static_cast<int16_t>(scaled >= 0.0F ? scaled + 0.5F : scaled - 0.5F);
}

uint8_t menuIndexForHoldDuration(unsigned long heldDurationMs) {
  constexpr uint8_t kMenuCycleSlots = kHoldMenuItemCount + 1;

  if (heldDurationMs < kMenuEntryHoldMs) {
    return 0;
  }

  const unsigned long menuElapsedMs = heldDurationMs - kMenuEntryHoldMs;
  const uint8_t cycleSlot =
      static_cast<uint8_t>((menuElapsedMs / kMenuStepIntervalMs) % kMenuCycleSlots);
  if (cycleSlot == kHoldMenuItemCount) {
    return 0;
  }

  return cycleSlot + 1;
}

uint8_t currentHoldMenu() {
  return menuIndexForHoldDuration(state.millisHeld);
}

void runHoldMenuAction(uint8_t menuIndex) {
  if (menuIndex == 1) {
    state.calibrationValue = calibrate();
  } else if (menuIndex == 2) {
    po2_change();
  } else if (menuIndex == 3) {
    buzzer_toggle();
  } else if (menuIndex == 4) {
    mod_unit_toggle();
  } else if (menuIndex == 5) {
    max_clear();
  }
}

bool isCalibrationValid(float value) {
  return value >= kMinValidCalibration && value <= kMaxValidCalibration;
}

void writeCalibration(uint16_t value) {
  const CalibrationData data = {kCalibrationMagic, value};
  const uint8_t *raw = reinterpret_cast<const uint8_t *>(&data);
  for (unsigned int i = 0; i < sizeof(CalibrationData); ++i) {
    EEPROM.update(kCalibrationAddress + i, raw[i]);
  }
}

void updateCalibrationScale(float calibrationValue) {
  state.calibrationValue = calibrationValue;
  state.calibrationScale =
      isCalibrationValid(calibrationValue)
          ? static_cast<float>(kAirCalibrationPercent) / calibrationValue
          : 0.0F;
}

void writeSettings() {
  SettingsData data = {kSettingsMagic,
                       static_cast<uint8_t>(roundToTenths(state.maxPo1)), 0};
  if (state.buzzerEnabled) {
    data.flags |= kSettingsBuzzerFlag;
  }
  if (state.modInFeet) {
    data.flags |= kSettingsModInFeetFlag;
  }
  EEPROM.put(kSettingsAddress, data);
}

void readSettings() {
  SettingsData data = {};
  EEPROM.get(kSettingsAddress, data);
  if (data.magic != kSettingsMagic) {
    logBootMessage(F("BOOT: settings defaults"));
    return;
  }

  if (data.maxPo1Tenths >= kMinPo2Tenths && data.maxPo1Tenths <= kMaxPo2Tenths) {
    state.maxPo1 = static_cast<float>(data.maxPo1Tenths) / 10.0F;
  }
  state.buzzerEnabled = (data.flags & kSettingsBuzzerFlag) != 0;
  state.modInFeet = (data.flags & kSettingsModInFeetFlag) != 0;
  logBootMessage(F("BOOT: settings loaded"));
}

void clearSettings() {
  EEPROM.update(kSettingsAddress, static_cast<uint8_t>(~kSettingsMagic));
}

bool consumeWakeMarker() {
  if (EEPROM.read(kWakeMarkerAddress) != kWakeMarkerMagic) {
    return false;
  }
  EEPROM.update(kWakeMarkerAddress, static_cast<uint8_t>(~kWakeMarkerMagic));
  return true;
}

bool settingsResetRequested() {
  const unsigned long startMs = millis();
  while (digitalRead(kButtonPin) == LOW) {
    if ((millis() - startMs) >= kSettingsResetHoldMs) {
      return true;
    }
    delay(kPausePollMs);
  }
  return false;
}

bool readCalibration(float &value) {
  CalibrationData data = {};
  uint8_t *raw = reinterpret_cast<uint8_t *>(&data);
  for (unsigned int i = 0; i < sizeof(CalibrationData); ++i) {
    raw[i] = EEPROM.read(kCalibrationAddress + i);
  }

  if (data.magic != kCalibrationMagic || !isCalibrationValid(data.value)) {
    return false;
  }

  value = data.value;
  return true;
}

void setup(void) {
  Serial.begin(kSerialBaudRate);
  logBootMessage(F("BOOT: serial"));

  pinMode(kButtonPin, INPUT_PULLUP);
  pinMode(kBuzzerPin, OUTPUT);
  digitalWrite(kBuzzerPin, LOW);
  delay(10);

  // A wake press from auto power-off is still held during this reboot; it
  // must not be mistaken for the hold-to-reset gesture.
  const bool wokeFromAutoOff = consumeWakeMarker();

  if (!wokeFromAutoOff && settingsResetRequested()) {
    // Button held through power-on: factory-reset the saved settings.
    clearSettings();
    logBootMessage(F("BOOT: settings reset"));
    while (digitalRead(kButtonPin) == LOW) {
      delay(kPausePollMs);
    }
  } else {
    readSettings();
  }

  // SSD1306_SWITCHCAPVCC = generate display voltage from 3.3V internally
  if (!display.begin(SSD1306_SWITCHCAPVCC, kScreenAddress)) {
    logBootMessage(F("BOOT: oled fail"));
    for (;;) {
    }  // Don't proceed, loop forever
  }
  logBootMessage(F("BOOT: oled ok"));

  if (!wokeFromAutoOff) {
    renderStartupScreen(display, VERSION);
    logBootMessage(F("BOOT: startup shown"));
    delay(kSplashScreenMs);
  }
  invalidateDisplaySnapshot();

  ads.setGain(GAIN_TWO);
  ads.setDataRate(RATE_ADS1115_250SPS);
  ads.begin(); // ads1115 start
  ads.startADCReading(ADS1X15_REG_CONFIG_MUX_DIFF_0_1, /*continuous=*/true);
  logBootMessage(F("BOOT: ads ok"));

  sensorAverage.clear();
  for (int cx = 0; cx < kRaSize; cx++) {
    delay(kAdsConversionSpacingMs);
    readSensor();
  }
  logBootMessage(F("BOOT: warmup ok"));

  if (!readCalibration(state.calibrationValue)) {
    logBootMessage(F("BOOT: calibrating"));
    updateCalibrationScale(calibrate());
    logBootMessage(F("BOOT: calibration done"));
  } else {
    updateCalibrationScale(state.calibrationValue);
    logBootMessage(F("BOOT: calibration loaded"));
  }

  if (wokeFromAutoOff) {
    // The wake press may still be held; ignore it until released so it does
    // not register as a new press (which would trigger the lock screen).
    state.ignoreHeldButton = true;
  }

  beep(1);
  logBootMessage(F("BOOT: ready"));
}

int calibrate() {
  renderCalibrationScreen(display);

  sensorAverage.clear();
  float result = 0.0F;
  for (int cx = 0; cx < kRaSize; cx++) {
    delay(kAdsConversionSpacingMs);
    readSensor();
  }
  result = sensorAverage.average();
  if (result < 0.0F) {
    result = -result;
  }
  if (result < kMinValidCalibration) {
    result = kMinValidCalibration;
  } else if (result > kMaxValidCalibration) {
    result = kMaxValidCalibration;
  }
  writeCalibration(static_cast<uint16_t>(result));
  updateCalibrationScale(result);

  beep(1);
  pauseWithPolling(kStatusScreenMs);
  invalidateDisplaySnapshot();
  state.activeFrames = 0;
  return result;
}

void analyze() {
  float currentmv = 0.0F;
  float result = 0.0F;
  float mv = 0.0F;
  DisplaySnapshot snapshot = {};

  currentmv = sensorAverage.average();
  if (currentmv < 0.0F) {
    currentmv = -currentmv;
  }
  mv = currentmv * kAdsMultiplier;

  if (state.calibrationScale <= 0.0F || mv < kMinValidMillivolts) {
    result = 0;
  } else {
    result = currentmv * state.calibrationScale;
  }
  if (result > 99.9F) {
    result = 99.9F;
  }

  snapshot.initialized = true;
  snapshot.sensorError = mv < kMinValidMillivolts || result <= 0;
  snapshot.resultTenths = roundToTenths(result);
  snapshot.mvHundredths = roundToHundredths(mv);
  snapshot.maxPo1Tenths = roundToTenths(state.maxPo1);
  snapshot.modInFeet = state.modInFeet;
  snapshot.blinkVisible = (state.activeFrames % 4) != 0;
  snapshot.holdMenu = currentHoldMenu();

  if (snapshot.sensorError) {
    if (lastDisplaySnapshot.initialized &&
        lastDisplaySnapshot.sensorError == snapshot.sensorError &&
        lastDisplaySnapshot.mvHundredths == snapshot.mvHundredths) {
      return;
    }

    lastDisplaySnapshot = snapshot;
    renderSensorErrorScreen(display);
  } else {
    if (result >= state.resultMax) {
      state.resultMax = result;
    }

    // A meaningful O2 change means the analyzer is in use; hold off auto power-off.
    const int16_t activityDelta = snapshot.resultTenths - state.activityResultTenths;
    if (activityDelta >= kActivityDeltaTenths || activityDelta <= -kActivityDeltaTenths) {
      state.activityResultTenths = snapshot.resultTenths;
      state.lastActivityMs = millis();
    }

    snapshot.resultMaxTenths = roundToTenths(state.resultMax);
    snapshot.modPrimaryTenths = roundToTenths(calculateModDepth(result, state.maxPo1));
    snapshot.modSecondaryTenths =
        roundToTenths(calculateModDepth(result, kDefaultMaxPo2));

    if (lastDisplaySnapshot.initialized &&
        !lastDisplaySnapshot.sensorError &&
        lastDisplaySnapshot.resultTenths == snapshot.resultTenths &&
        lastDisplaySnapshot.resultMaxTenths == snapshot.resultMaxTenths &&
        lastDisplaySnapshot.mvHundredths == snapshot.mvHundredths &&
        lastDisplaySnapshot.maxPo1Tenths == snapshot.maxPo1Tenths &&
        lastDisplaySnapshot.modInFeet == snapshot.modInFeet &&
        lastDisplaySnapshot.modPrimaryTenths == snapshot.modPrimaryTenths &&
        lastDisplaySnapshot.modSecondaryTenths == snapshot.modSecondaryTenths &&
        lastDisplaySnapshot.blinkVisible == snapshot.blinkVisible &&
        lastDisplaySnapshot.holdMenu == snapshot.holdMenu) {
      return;
    }
    lastDisplaySnapshot = snapshot;
    renderAnalyzerScreen(display, snapshot);
  }
}

void lock_screen(unsigned long pause = kLockScreenMs) {
  beep(1);
  renderLockScreen(display);
  const unsigned long startMs = millis();
  while ((millis() - startMs) < pause) {
    if (digitalRead(kButtonPin) == LOW) {
      break;
    }
    sampleSensorIfDue();
    delay(kPausePollMs);
  }
  invalidateDisplaySnapshot();
  state.activeFrames = 0;
  state.firstPressTime = millis();
}

void po2_change() {
  const int16_t t = roundToTenths(state.maxPo1);
  state.maxPo1 =
      (t == roundToTenths(1.3F)) ? 1.4F : (t == roundToTenths(1.4F)) ? 1.5F : 1.3F;
  const uint16_t newTenths = static_cast<uint16_t>(roundToTenths(state.maxPo1));
  writeSettings();

  renderPo2Screen(display, newTenths);
  beep(1);
  pauseWithPolling(kStatusScreenMs);
  invalidateDisplaySnapshot();
  state.activeFrames = 0;
}

void buzzer_toggle() {
  state.buzzerEnabled = !state.buzzerEnabled;
  writeSettings();

  renderBuzzerScreen(display, state.buzzerEnabled);

  if (state.buzzerEnabled) {
    beep(1);
  }

  pauseWithPolling(kStatusScreenMs);
  invalidateDisplaySnapshot();
  state.activeFrames = 0;
}

void mod_unit_toggle() {
  state.modInFeet = !state.modInFeet;
  writeSettings();

  renderModUnitScreen(display, state.modInFeet);
  beep(1);
  pauseWithPolling(kStatusScreenMs);
  invalidateDisplaySnapshot();
  state.activeFrames = 0;
}

void onPowerOffWake() {}

bool powerOffWarningCancelled() {
  for (uint8_t secondsLeft = kPowerOffWarningSeconds; secondsLeft > 0; --secondsLeft) {
    const unsigned long cycleStartMs = millis();
    renderPowerOffWarningScreen(display, secondsLeft);
    if (secondsLeft == kPowerOffWarningSeconds) {
      beep(1);
    }

    while ((millis() - cycleStartMs) < kMsPerSecond) {
      if (digitalRead(kButtonPin) == LOW) {
        while (digitalRead(kButtonPin) == LOW) {
          delay(kPausePollMs);
        }
        return true;
      }
      handleSerialCommands();
      sampleSensorIfDue();
      delay(kPausePollMs);
    }
  }

  return false;
}

void powerDown() {
  if (powerOffWarningCancelled()) {
    const unsigned long now = millis();
    state.lastActivityMs = now;
    state.firstPressTime = now;
    state.activeFrames = 0;
    invalidateDisplaySnapshot();
    return;
  }

  renderAutoOffScreen(display);
  beep(2);
  pauseWithPolling(kStatusScreenMs);

  display.ssd1306_command(SSD1306_DISPLAYOFF);
  // Drop the ADS1115 back to single-shot; it powers itself down after one
  // final conversion.
  ads.startADCReading(ADS1X15_REG_CONFIG_MUX_DIFF_0_1, /*continuous=*/false);
  // Mark the next reboot as a wake so the held wake press is not treated as
  // a settings-reset hold.
  EEPROM.update(kWakeMarkerAddress, kWakeMarkerMagic);

  attachInterrupt(digitalPinToInterrupt(kButtonPin), onPowerOffWake, LOW);
  set_sleep_mode(SLEEP_MODE_PWR_DOWN);
  noInterrupts();
  sleep_enable();
#if defined(BODS) && defined(BODSE)
  sleep_bod_disable();
#endif
  interrupts();
  sleep_cpu();
  sleep_disable();
  detachInterrupt(digitalPinToInterrupt(kButtonPin));

  // Button pressed: reboot through the watchdog for a clean re-init.
  wdt_enable(WDTO_15MS);
  for (;;) {
  }
}

void max_clear() {
  state.resultMax = 0;
  renderMaxClearedScreen(display);
  beep(1);
  pauseWithPolling(kStatusScreenMs);
  invalidateDisplaySnapshot();
  state.activeFrames = 0;
}

void loop(void) {
  handleSerialCommands();
  sampleSensorIfDue();

  const unsigned long now = millis();
  const int current = digitalRead(kButtonPin);

  if (state.ignoreHeldButton) {
    // Consume the still-held wake press from auto power-off; treat the
    // button as inactive until it has been released once.
    if (current == HIGH) {
      state.ignoreHeldButton = false;
      state.firstPressTime = now;
      state.lastActivityMs = now;
    }
    state.millisHeld = 0;
    state.previousButtonState = current;
  } else {
    if (current == LOW && state.previousButtonState == HIGH &&
        (now - state.firstPressTime) > kButtonDebounceMs) {
      state.firstPressTime = now;
      state.activeFrames = 17;
      state.lastActivityMs = now;
    }

    const unsigned long releasedHoldMs =
        (current == HIGH && state.previousButtonState == LOW)
            ? (now - state.firstPressTime)
            : 0;
    state.millisHeld = (current == LOW) ? (now - state.firstPressTime) : 0;

    if (releasedHoldMs > 2) {
      state.lastActivityMs = now;
      if (releasedHoldMs < kMenuEntryHoldMs) {
        lock_screen();
      } else {
        runHoldMenuAction(menuIndexForHoldDuration(releasedHoldMs));
      }

      state.millisHeld = 0;
      state.firstPressTime = now;
    }

    state.previousButtonState = current;
  }

  if ((now - state.lastActivityMs) >= kAutoPowerOffMs) {
    // Shows a cancellable countdown; if not cancelled, sleeps and only
    // returns via a button-press watchdog reboot.
    powerDown();
  }

  if ((now - state.lastUiRefreshMs) >= kUiRefreshIntervalMs) {
    state.lastUiRefreshMs = now;
    analyze();
    state.activeFrames++;
  }

  // Idle until the next timer tick (~1ms); millis, serial, and tone keep running.
  set_sleep_mode(SLEEP_MODE_IDLE);
  sleep_mode();
}

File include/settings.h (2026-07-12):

/*****************************************************************************
* 
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
*****************************************************************************/

#pragma once

#include <Arduino.h>

#define VERSION "V1.2"

constexpr uint8_t kCalibrationMagic = 0xA5;
constexpr int kCalibrationAddress = 0;
constexpr uint8_t kSettingsMagic = 0x5A;
constexpr int kSettingsAddress = 8;
constexpr uint8_t kWakeMarkerMagic = 0xC3;
constexpr int kWakeMarkerAddress = 12;

constexpr int kRaSize = 20;
constexpr unsigned long kSensorSampleIntervalMs = 50;

constexpr int kScreenWidth = 128;
constexpr int kScreenHeight = 64;
constexpr int kOledReset = 4;
constexpr uint8_t kScreenAddress = 0x3C;

constexpr uint8_t kButtonPin = 2;
constexpr uint8_t kBuzzerPin = 3;
constexpr bool kBuzzerEnabledByDefault = true;
constexpr bool kBootDebugLogging = false;
constexpr unsigned long kSerialBaudRate = 57600;
constexpr char kScreenshotCommand = 's';

constexpr unsigned long kMenuEntryHoldSeconds = 2;
constexpr unsigned long kMenuStepIntervalMs = 1100;
constexpr unsigned long kStatusScreenMs = 1200;
constexpr unsigned long kLockScreenMs = 5000;
constexpr unsigned long kSplashScreenMs = 1200;
constexpr unsigned long kAutoPowerOffMs = 5UL * 60UL * 1000UL;
constexpr uint8_t kPowerOffWarningSeconds = 10;
constexpr int16_t kActivityDeltaTenths = 3;
constexpr unsigned long kSettingsResetHoldMs = 1000;
constexpr bool kModInFeetByDefault = true;

constexpr double kMinValidCalibration = 100.0;
constexpr double kMaxValidCalibration = 32000.0;
constexpr double kMinValidMillivolts = 0.05;
constexpr double kAirCalibrationPercent = 20.9;

constexpr float kAdsMultiplier = 0.0625F;
constexpr float kFeetPerMeter = 3.28084F;
constexpr float kDefaultMinPo2 = 1.4F;
constexpr float kDefaultMaxPo2 = 1.6F;

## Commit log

2026-04-19 Updated wiring diagram
2026-04-19 Updates documentation and images
    [back_cap.stl, back_half.stl, battery-sensor_cover.stl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]
2026-07-12 Minor performance improvements, auto-power display, and settings persistence

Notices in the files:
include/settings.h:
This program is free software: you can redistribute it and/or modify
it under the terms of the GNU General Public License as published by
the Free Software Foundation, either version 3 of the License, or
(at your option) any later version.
